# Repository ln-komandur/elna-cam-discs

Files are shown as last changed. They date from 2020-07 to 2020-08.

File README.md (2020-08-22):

# 3D Printing Cams / Discs for Vintage Elna Sewing Machines (Supermatic, SU etc.)

The source code here is written to work in **_OpenSCAD_** to 3D print Cams / Discs for Vintage Elna Sewing Machines that will fit Elna Supermatic, Elna SU and the other machines in that Elna family.

## OpenSCAD code covers

1. Basic code capturing the cam's dimensions
1. Double cams
1. Single cams
1. An aggregator to print 4 single cams and 1 double cam in one single print job

## Good references 

The below are in German
1. Update zum Elna-Disc Projekt - Starship Factory - https://starship-factory.ch/2013/10/13/update-zum-elna-disc-projekt/
1. ELNA Supermatic-Musterdiscs selber herstellen - https://starship-factory.ch/2013/10/09/elna-supermatic-musterdiscs-selber-herstellen/ - this link provides measurements
1. Starship Factory - Tag nähen - https://starship-factory.ch/tags/n%C3%A4hen/
1. Source code for these references is found at - https://github.com/onitake/elna-discs 

## Software requirements

1. **_OpenSCAD_** from https://www.openscad.org/downloads.html

## Details & Dimensions
1. Refer https://github.com/ln-komandur/elna-cam-discs/blob/master/Elna%20Cam%20Dimensions.md

## Output

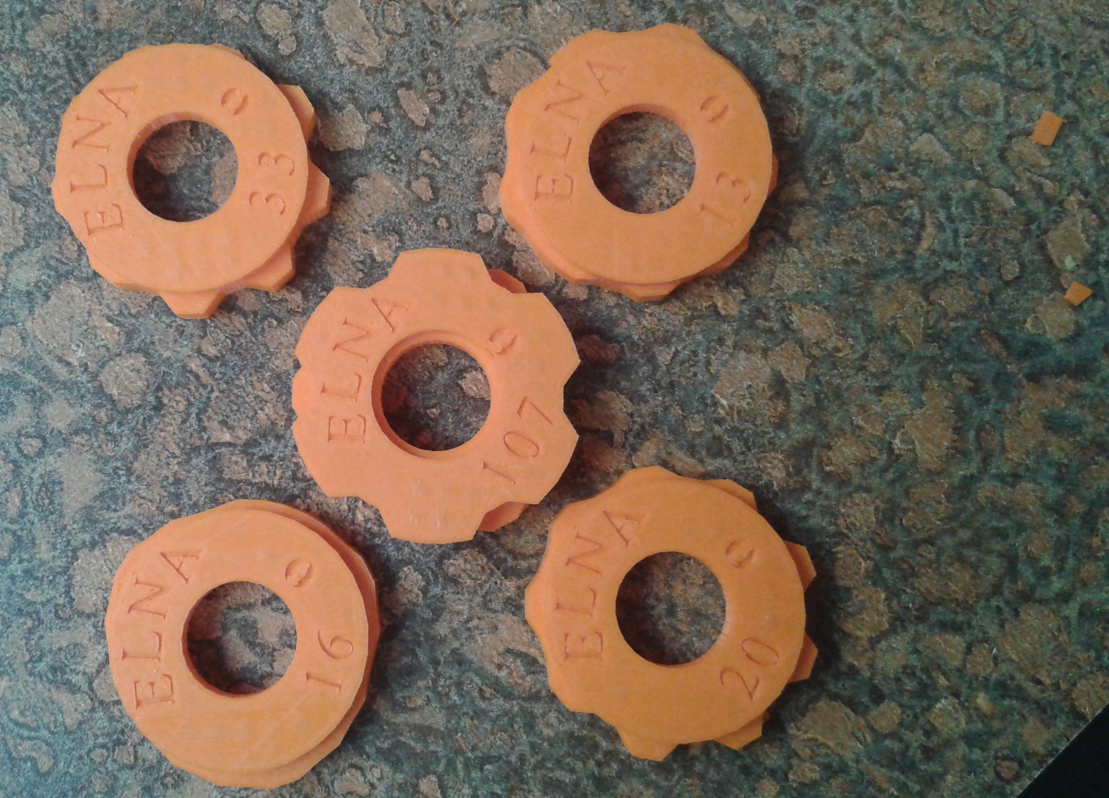
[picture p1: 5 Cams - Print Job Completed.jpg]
5 cams printed from 1 print job


## Video
https://youtu.be/hsAO7MdCPhM

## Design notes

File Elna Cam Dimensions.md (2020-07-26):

# Single cams / discs dimensions
They have lobes only on their lower half. They serve to move the needle between left and right stich positions
1.   disc_thickness = 7mm;

# Double cams / discs dimensions
They have lobes on the upper half in addition to the lower half. 
They are thicker than single cams by 2mm to accommodate lobes on the upper half. But their inner hole is the same height as single cams. 
There is an additional bigger hole (2mm depth) on the top side of these cams just like the one on their bottom side to let them "click in" and "click out" of the cam holder. (see pictures)
1.   double_disc_thickness = 9mm;

#  Dimensions Common to both single and  double cam / disc 
These align with the cam holder mechanism in the sewing machine for either cam types to *click in* and fit perfectly

1. thickest_cyl_rad = 17mm - radius of the thickest cam cylinder. This is the basic cylinder on whose circumference the lobes will sit on. 
1. lobe_thickness = 4.5mm - height / thickness of each lobe that sits on the circumference of the basic cam cylinder.
1. inner_hole_rad = 8.25mm - radius of the inner hole in the cam cylinder. This hole is cut to make the cam go on the cam holder shaft.
1. hole_bigger_rad = 9.5mm - radius of the lower part of the inner hole in the cam cylinder. It is slightly bigger.
1. bigger_hole_ht = 1.5mm - height of the lower part of the inner hole in the cam cylinder. It is slightly bigger.
1. cut_errors = 0.1mm - this decides the finess of the printed sides. It also depends on the settings on the 3D printer. 
1. hole_cone_ht = 1.5mm - the height of the cone that tapers the bigger inner hole to the smaller inner hole. 
1. skirting = 0;

## Transport hole
This aligns the cam to the pin in the cam holder mechanism. It is 3D printed as a void cuboid.

1. gap_to_transporthole = 1; distance of the transport hole from the edge of the bigger inner hole
1. transporthole_width = 3mm;
1. transporthole_depth = 5.5mm;
1. transporthole_length  = 4mm;

# Design considerations from sewing maching cam rotation mechanism
1. Each rotation of a cam / cam holder shaft makes 18 stiches / needle punches
1. The lower lobes on the body of a cam of either type (single / double) serve to move the needle between left and right stich positions
1. The upper lobes on the body of a double cam serve to move the cloth forwards and backwards

# Size of letters on the cam
1. Font type - ?
1. Font size - ?
1. Depth - ?

# Printing considerations
1. Cams print right side up. i.e.
   1. letters are on the top side of the print job
   1. transport hole is on the bottom side of the print job 
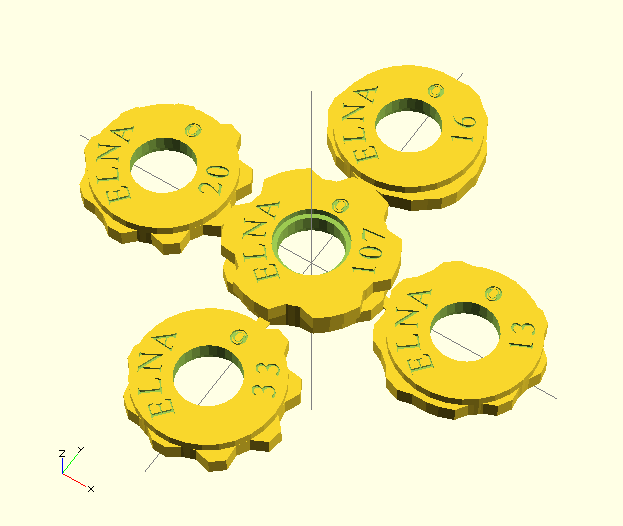
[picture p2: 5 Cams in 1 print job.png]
5 Cams in 1 print job
   1. 
1. After 3D printing, the 5 cams can be snapped free from each other.

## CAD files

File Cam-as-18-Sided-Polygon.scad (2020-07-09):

/*  Provides a common method / function / module to 3D Print an 18 sided polygon for a cam used by Elna Supermatic, Elna SU machines sewing machines, matching with the 18 punches made by the needle per each rotation of a cam.

    Copyright (C) 2020  L Komandur

    This program is free software: you can redistribute it and/or modify
    it under the terms of the GNU General Public License as published by
    the Free Software Foundation, either version 3 of the License, or
    (at your option) any later version.

    This program is distributed in the hope that it will be useful,
    but WITHOUT ANY WARRANTY; without even the implied warranty of
    MERCHANTABILITY or FITNESS FOR A PARTICULAR PURPOSE.  See the
    GNU General Public License for more details.

    You should have received a copy of the GNU General Public License
    along with this program.  If not, see <https://www.gnu.org/licenses/>.
*/

thickest_cyl_rad = 17;
skirting_width=1.5;

angle_of_side = 11;
min_radius = thickest_cyl_rad+skirting_width;

module plotpoly(p1,p2,p3,p4,p5,p6,p7,p8,p9,p10,p11,p12,p13,p14,p15,p16,p17,p18) {
	//scale ([-1,1])
	polygon( points = [
	[(min_radius + p1)*sin(0-angle_of_side/2), (min_radius + p1)*cos(0-angle_of_side/2)],
	[(min_radius + p1)*sin(0+angle_of_side/2), (min_radius + p1)*cos(0+angle_of_side/2)],
	[(min_radius + p2)*sin(20-angle_of_side/2), (min_radius + p2)*cos(20-angle_of_side/2)],	
	[(min_radius + p2)*sin(20+angle_of_side/2), (min_radius + p2)*cos(20+angle_of_side/2)],	
	[(min_radius + p3)*sin(40-angle_of_side/2), (min_radius + p3)*cos(40-angle_of_side/2)],	
	[(min_radius + p3)*sin(40+angle_of_side/2), (min_radius + p3)*cos(40+angle_of_side/2)],	
	[(min_radius + p4)*sin(60-angle_of_side/2), (min_radius + p4)*cos(60-angle_of_side/2)],	
	[(min_radius + p4)*sin(60+angle_of_side/2), (min_radius + p4)*cos(60+angle_of_side/2)],	
	[(min_radius + p5)*sin(80-angle_of_side/2), (min_radius + p5)*cos(80-angle_of_side/2)],	
	[(min_radius + p5)*sin(80+angle_of_side/2), (min_radius + p5)*cos(80+angle_of_side/2)],	
	[(min_radius + p6)*sin(100-angle_of_side/2), (min_radius + p6)*cos(100-angle_of_side/2)],	
	[(min_radius + p6)*sin(100+angle_of_side/2), (min_radius + p6)*cos(100+angle_of_side/2)],	
	[(min_radius + p7)*sin(120-angle_of_side/2), (min_radius + p7)*cos(120-angle_of_side/2)],	
	[(min_radius + p7)*sin(120+angle_of_side/2), (min_radius + p7)*cos(120+angle_of_side/2)],	
	[(min_radius + p8)*sin(140-angle_of_side/2), (min_radius + p8)*cos(140-angle_of_side/2)],	
	[(min_radius + p8)*sin(140+angle_of_side/2), (min_radius + p8)*cos(140+angle_of_side/2)],	
	[(min_radius + p9)*sin(160-angle_of_side/2), (min_radius + p9)*cos(160-angle_of_side/2)],	
	[(min_radius + p9)*sin(160+angle_of_side/2), (min_radius + p9)*cos(160+angle_of_side/2)],	
	[(min_radius + p10)*sin(180-angle_of_side/2), (min_radius + p10)*cos(180-angle_of_side/2)],	
	[(min_radius + p10)*sin(180+angle_of_side/2), (min_radius + p10)*cos(180+angle_of_side/2)],	
	[(min_radius + p11)*sin(200-angle_of_side/2), (min_radius + p11)*cos(200-angle_of_side/2)],	
	[(min_radius + p11)*sin(200+angle_of_side/2), (min_radius + p11)*cos(200+angle_of_side/2)],	
	[(min_radius + p12)*sin(220-angle_of_side/2), (min_radius + p12)*cos(220-angle_of_side/2)],	
	[(min_radius + p12)*sin(220+angle_of_side/2), (min_radius + p12)*cos(220+angle_of_side/2)],	
	[(min_radius + p13)*sin(240-angle_of_side/2), (min_radius + p13)*cos(240-angle_of_side/2)],	
	[(min_radius + p13)*sin(240+angle_of_side/2), (min_radius + p13)*cos(240+angle_of_side/2)],	
	[(min_radius + p14)*sin(260-angle_of_side/2), (min_radius + p14)*cos(260-angle_of_side/2)],	
	[(min_radius + p14)*sin(260+angle_of_side/2), (min_radius + p14)*cos(260+angle_of_side/2)],	
	[(min_radius + p15)*sin(280-angle_of_side/2), (min_radius + p15)*cos(280-angle_of_side/2)],	
	[(min_radius + p15)*sin(280+angle_of_side/2), (min_radius + p15)*cos(280+angle_of_side/2)],	
	[(min_radius + p16)*sin(300-angle_of_side/2), (min_radius + p16)*cos(300-angle_of_side/2)],		
	[(min_radius + p16)*sin(300+angle_of_side/2), (min_radius + p16)*cos(300+angle_of_side/2)],		
	[(min_radius + p17)*sin(320-angle_of_side/2), (min_radius + p17)*cos(320-angle_of_side/2)],	
	[(min_radius + p17)*sin(320+angle_of_side/2), (min_radius + p17)*cos(320+angle_of_side/2)],	
	[(min_radius + p18)*sin(340-angle_of_side/2), (min_radius + p18)*cos(340-angle_of_side/2)],
	[(min_radius + p18)*sin(340+angle_of_side/2), (min_radius + p18)*cos(340+angle_of_side/2)]
	]);

}

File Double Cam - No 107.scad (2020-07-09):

/*  3D Prints a "double cam" similar to Cam No 107 of Elna Supermatic, Elna SU machines sewing machines.

    Copyright (C) 2020  L Komandur

    This program is free software: you can redistribute it and/or modify
    it under the terms of the GNU General Public License as published by
    the Free Software Foundation, either version 3 of the License, or
    (at your option) any later version.

    This program is distributed in the hope that it will be useful,
    but WITHOUT ANY WARRANTY; without even the implied warranty of
    MERCHANTABILITY or FITNESS FOR A PARTICULAR PURPOSE.  See the
    GNU General Public License for more details.

    You should have received a copy of the GNU General Public License
    along with this program.  If not, see <https://www.gnu.org/licenses/>.
*/

use <Cam-as-18-Sided-Polygon.scad>

double_disc_thickness = 9;

disc_thickness = 9; // 7 for single, 9 for double
thickest_cyl_rad = 17;

lobe_thickness = 4.5;
inner_hole_rad = 8.25;
hole_bigger_rad = 9.5;
bigger_hole_ht = 1.5;
cut_errors = 0.1;
hole_cone_ht = 1.5;
skirting = 0;


gap_bet_cloth_needle_cams = disc_thickness-2*skirting-2*lobe_thickness;

gap_to_transporthole = 1;

transporthole_width = 3;
transporthole_depth = 5.5;
transporthole_length  = 4;

peak=3;
c=peak/2;
l=0;
r=peak;
cl=peak/4;
cr=peak*3/4;
skirting_width=1.5;
min_radius = thickest_cyl_rad+skirting_width;
phase_diff = 60;

module letter(l,font="font.dxf",h=100,i=0) {
	union() {
		linear_extrude( height=h) import(font, layer=l[i]);
		translate([dxf_dim(file=font, name="advx",layer=l[i]),
			dxf_dim(file=font, name="advy",layer=l[i]),
			0])
			child();
	}
}

module word(wrd,font="font.dxf",h=100,i=0) {
	if(i < len(wrd)) {
		letter(wrd,font,h,i) word(wrd,font,h,i+1);
	} else {
		child();
	}
}


module print_d107_cam(x,y) {

	translate([x, y, 0]) rotate(a=[0,0,0]) difference() {
		union() {
			// tall INNER tall cylinder that excludes skirting 
		cylinder(h = disc_thickness, r = thickest_cyl_rad);
	
			// 2nd bigger cylinder shared between 2 cams and skirting; any sewing information would go here.
	
		translate([0, 0, skirting]) cylinder(h = disc_thickness - skirting*2, r = thickest_cyl_rad + skirting_width);
		translate([0, 0, skirting])
		linear_extrude (height  = lobe_thickness)
			plotpoly(c,c,l,c,c,r,c,c,l,c,c,r,c,c,l,c,c,r);
		
		// Upper cam for cloth movement
		rotate(a=[0,0,phase_diff])
		translate([0, 0, lobe_thickness])
		linear_extrude (height  = lobe_thickness)
			plotpoly(r,r,l,r,r,l,r,r,l,r,r,l,r,r,l,r,r,l);
		
	
		}
	
		// Subtract the inner hole. Be very generous.
		translate([0, 0, disc_thickness/2])
			cylinder(h = disc_thickness+1, r = inner_hole_rad, center = true);
	
		// Subtract the lower wider hole
		translate([0, 0, -cut_errors])
			cylinder(h = bigger_hole_ht+cut_errors, r = hole_bigger_rad);
	
	
		// Subtract the cone between wide hole and smaller hole.
		translate([0, 0, bigger_hole_ht-cut_errors])
			cylinder(h = hole_cone_ht, r1 = hole_bigger_rad, r2 = inner_hole_rad);
	
		// Subtract the upper cone the disk locks on the sewing machine post (only for double cams).
		translate([0, 0, double_disc_thickness-skirting-2+cut_errors])
			cylinder(h = 2, r = hole_bigger_rad);
	
		// Initials on the side of transport hole as depressions (top side while printing).
	
		for (letter_depth = [1:6])
		{
			rotate(a=[0, 0, 0]) translate([-2.25, 10.5, disc_thickness-0.1*letter_depth]) scale(0.0015) letter("O");
			rotate(a=[0, 0, 0]) translate([-1.5, 11.25, disc_thickness-0.1*letter_depth]) scale(0.001) letter("O");
			rotate(a=[0, 0, 140]) translate([-8, 10, disc_thickness-0.1*letter_depth]) scale(0.002) letter("E");
			rotate(a=[0, 0, 130]) translate([-4, 11, disc_thickness-0.1*letter_depth]) scale(0.002) letter("L");
			rotate(a=[0, 0, 120]) translate([-0, 11, disc_thickness-0.1*letter_depth]) scale(0.002) letter("N");
			rotate(a=[0, 0, 110]) translate([4, 10, disc_thickness-0.1*letter_depth]) scale(0.002) letter("A");

			rotate(a=[0, 0, 115]) translate([-8, -16, disc_thickness-0.1*letter_depth]) scale(0.002) letter("1");
			rotate(a=[0, 0, 115]) translate([-3, -17, disc_thickness-0.1*letter_depth]) scale(0.002) letter("0");
			rotate(a=[0, 0, 115]) translate([2, -17,disc_thickness-0.1*letter_depth]) scale(0.002) letter("7");
		}
		// Transport hole made as a rectangular  hole
		difference() {
			rotate(a=[0, 0, 0]) translate([0, hole_bigger_rad + gap_to_transporthole + transporthole_length/2, transporthole_depth/2-cut_errors])
				cube(size = [transporthole_width, transporthole_length, transporthole_depth], center = true);
	
		}
	}
}

print_d107_cam(0,0);

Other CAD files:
font.dxf
Five Cams in single print job.scad
Single Cam - No 13.scad
Single Cam - No 16.scad
Single Cam - No 20.scad
Single Cam - No 33.scad

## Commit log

2020-07-09 Image - OpenSCAD rendering "5 Cams in 1 print job"
2020-07-09 OpenSCAD source files to print 5 cams
    OpenSCAD source files to print 5 cams
    [Cam-as-18-Sided-Polygon.scad, Double Cam - No 107.scad, Five Cams in single print job.scad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]
2020-07-09 Font to print letter on cams
    Font file to print letter on cams
    [font.dxf]
2020-07-10 Double cam details & Printing considerations
    Added double cam details and Printing considerations
2020-07-26 Initial
    5 Cams - Print Job Completed
